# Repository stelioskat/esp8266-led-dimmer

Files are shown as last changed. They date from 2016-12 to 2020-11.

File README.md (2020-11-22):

# ESP8266 LED Dimmer (MQTT controlled)

1. [Layout](#layout)
  1. [Parts](#parts)
  2. [Schematic](#schematic)
2. [Firmware](#firmware)
  1. [MQTT](#mqtt)

This is a very simple wifi enabled (ESP8266 12e) LED dimmer for single colored LED strips. 

Its purpose was originally to be controlled by Node-RED (http://nodered.org) and node-red-contrib-homekit (https://flows.nodered.org/node/node-red-contrib-homekit) using MQTT events. Thus, one could control this with Apple Homekit.

Of course by using MQTT you can control it with whatever you like and not necessarily with Apple Homekit.

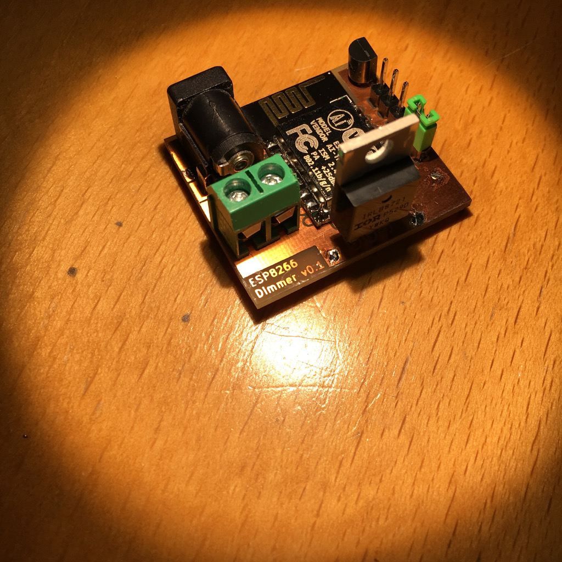
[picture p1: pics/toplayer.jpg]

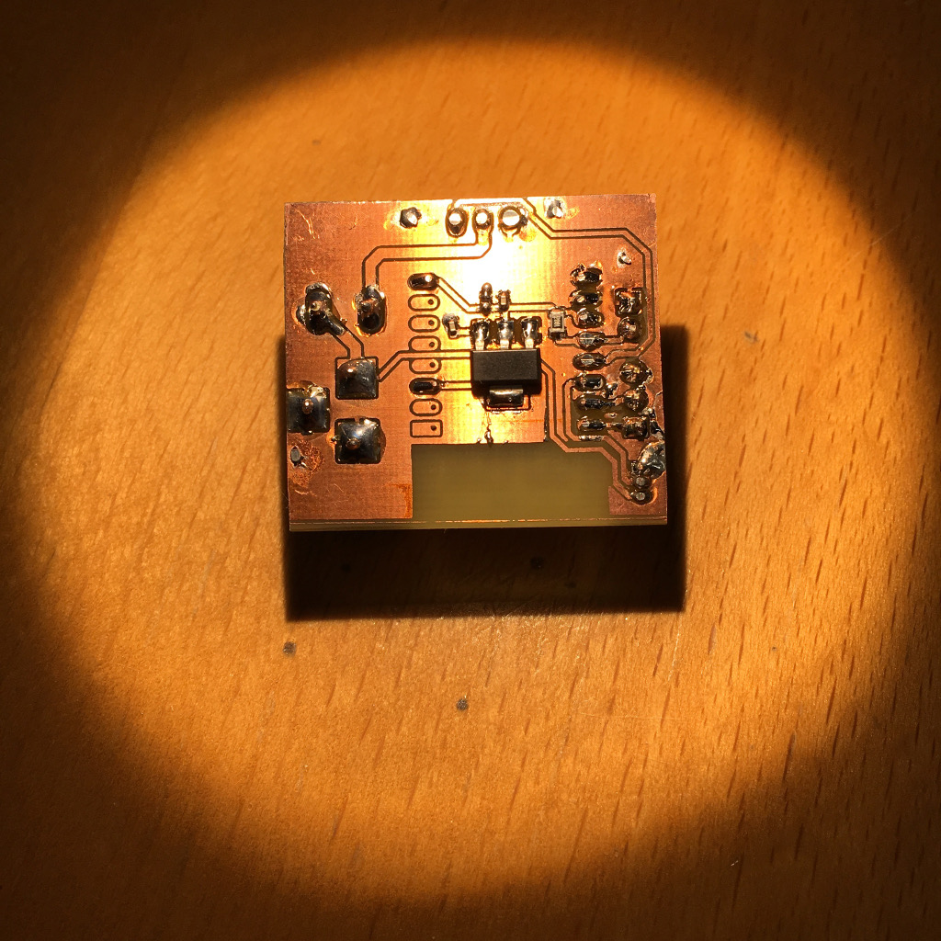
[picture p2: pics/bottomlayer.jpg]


## Layout

The layout is made with KiCad but I have also included an screenshot of the schematic, in case you want to make your own PCB with another software. You could simply produce this PCB for example by uploading the `ESPDimmer.kicad_pcb` file directly in [AISLER](https://go.aisler.net) .

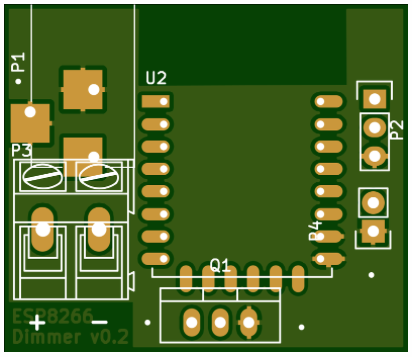
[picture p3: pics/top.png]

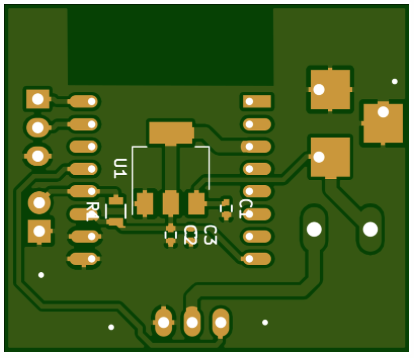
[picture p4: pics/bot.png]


### Parts
<table>
<tr>
  <th>
    Nr.
  </th>
  <th>
    Part
  </th>
  <th>
    Package
  </th>
  <th>
    Qty.
   </th>
</tr>
<tr>
  <td>1</td>
  <td>Capacitor 100nF</td>
  <td>0402</td>
  <td>2</td>
</tr>
<tr>
  <td>2</td>
  <td>Capacitor 1uF</td>
  <td>Package 0402</td>
  <td>1</td>
</tr>
<tr>
  <td>3</td>
  <td>Resistor 10k</td>
  <td>Package 0805</td>
  <td>1</td>
</tr>
<tr>
  <td>4</td>
  <td>Voltage regulator TLV1117</td>
  <td>SOT-223</td>
  <td>1</td>
</tr>
<tr>
  <td>5</td>
  <td>AK300-2 Terminal for LED strip</td>
  <td>-</td>
  <td>1</td>
</tr>
<tr>
  <td>6</td>
  <td>ESP8266-12E</td>
  <td></td>
  <td>1</td>
</tr>
<tr>
  <td>7</td>
  <td>Standard barrel jack for power supply</td>
  <td></td>
  <td>1</td>
</tr>
 <tr>
  <td>8</td>
  <td>30V Single N-Channel Power MOSFET</td>
  <td>TO-220</td>
  <td>1</td>
</tr>
</table>

### Schematic

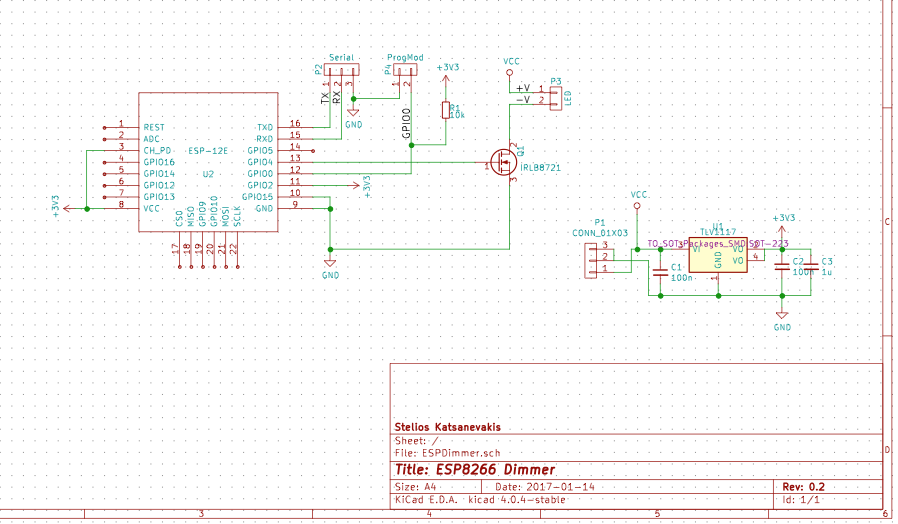
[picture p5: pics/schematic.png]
Schematic


## Firmware

The firmware can be compiled in Arduino IDE using the available ESP8266 package. In order to flash the firmware you will need a USB-to-Serial adapter such as the FTDI232 that I am using (https://github.com/jandelgado/arduino/wiki/FTDI232-USB-to-Serial-converter). Keep in mind that you will have to update the Wifi credentials and also the MQTT broker hostname and port to fit your own.

Of course, you could write your own firmware or you use another one since this is basically a breakout board.

### MQTT

The default firmware subscribes to the topic "/light/1" and expects the following JSON messages to control the LED strip and its brightness.

- Turn on command:
```
{"On":1}
```
- Turn off command:
```
{"On":0}
```
- Set brightness level:
```
{"Brightness":<A VALUE BETWEEN 0 AND 100>}
```

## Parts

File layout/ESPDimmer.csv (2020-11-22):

Id | Designator | Package | Quantity | Designation | Supplier and ref
1 | C1,C2 | C_0402 | 2 | 100n
2 | P2 | Socket_Strip_Straight_1x03 | 1 | Serial
3 | P4 | Socket_Strip_Straight_1x02 | 1 | ProgMod
4 | R1 | R_0805 | 1 | 10k
5 | U1 | SOT-223 | 1 | TLV1117
6 | P3 | AK300-2 | 1 | LED
7 | U2 | ESP-12E | 1 | ESP-12E
8 | Q1 | TO-220_Neutral123_Vertical | 1 | IRLB8721
9 | P1 | BARREL_JACK | 1 | CONN_01X03
10 | C3 | C_0402 | 1 | 1u

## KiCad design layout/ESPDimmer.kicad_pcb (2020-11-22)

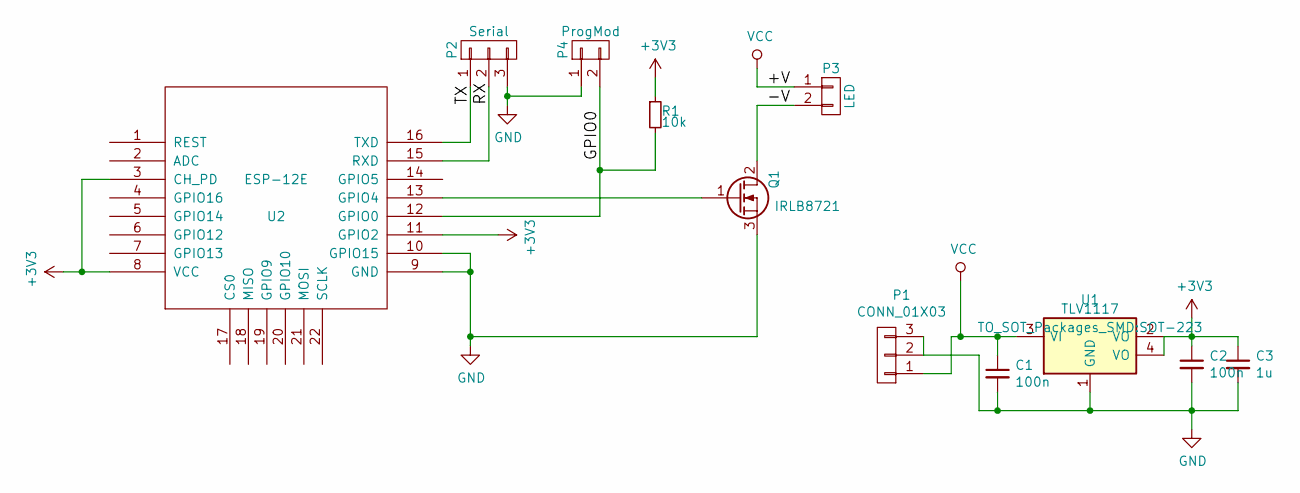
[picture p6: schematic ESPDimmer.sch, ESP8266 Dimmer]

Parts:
C1, C2: 100n; C_0402
C3: 1u; C_0402
P1: CONN_01X03; BARREL_JACK
P2: Serial; Socket_Strip_Straight_1x03
P3: LED; AK300-2
P4: ProgMod; Socket_Strip_Straight_1x02
Q1: IRLB8721; TO-220_Neutral123_Vertical
R1: 10k; R_0805
U1: TLV1117; SOT-223
U2: ESP-12E

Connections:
+3V3: C2.1, C3.1, R1.1, U1.2 (VO), U1.4 (VO), U2.3 (CH_PD), U2.8 (VCC), U2.11 (GPIO2)
/-V: P3.2, Q1.2 (D)
/GPIO0: P4.2, R1.2, U2.12 (GPIO0)
/RX: P2.2, U2.15 (RXD)
/TX: P2.1, U2.16 (TXD)
GND: C1.2, C2.2, C3.2, P1.2, P1.3, P2.3, P4.1, Q1.3 (S), U1.1 (GND), U2.9 (GND), U2.10 (GPIO15)
unnamed: Q1.1 (G), U2.13 (GPIO4)
VCC: C1.1, P1.1, P3.1, U1.3 (VI)

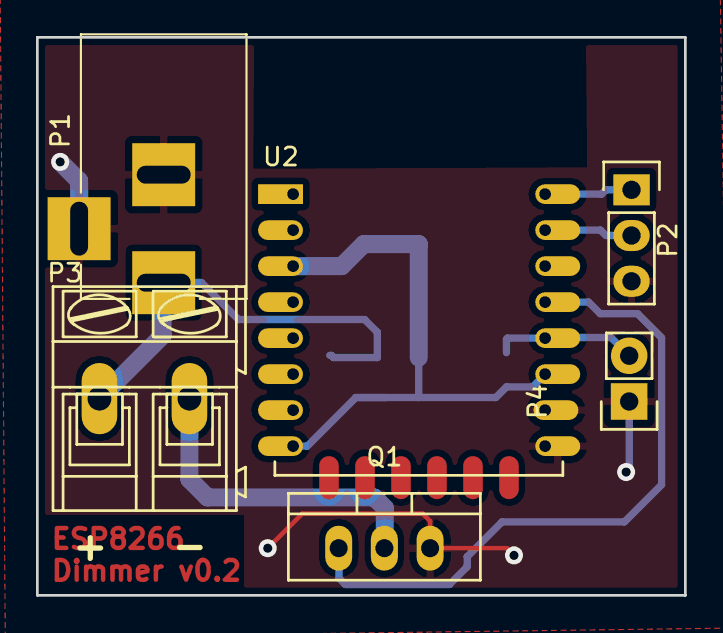
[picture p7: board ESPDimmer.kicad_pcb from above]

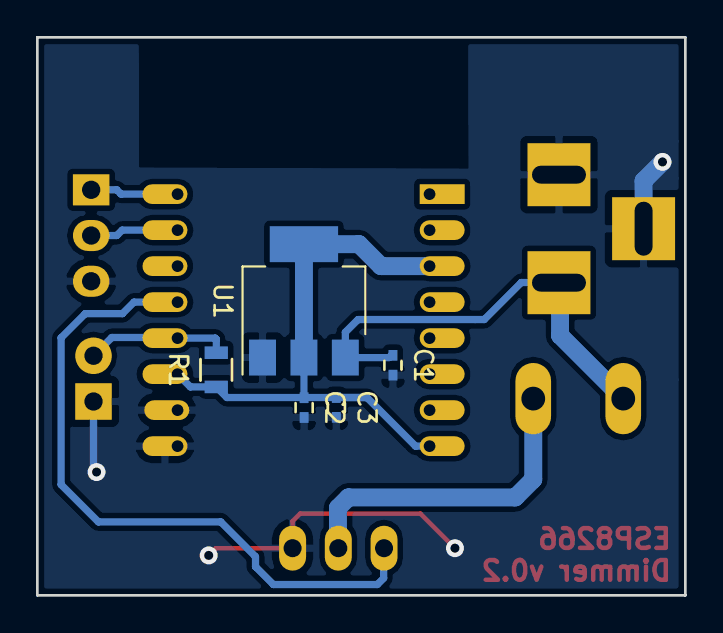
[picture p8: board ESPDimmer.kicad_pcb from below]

Board: 2 copper layers, 36.0 x 31.0 mm, 11 parts (5 on the bottom side), 8 nets.

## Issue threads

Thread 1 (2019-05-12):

two led strips

VOVAiS, 2019-05-12:
Hello.
Can version of your sketch in two led strips?

stelioskat, 2019-06-13:
Hi. Do you mean to drive them individually or just connect them in parallel?

VOVAiS, 2019-06-13:
drive them individually

stelioskat, 2019-06-14:
this would require a second transistor. You could e.g. replicate in GPIO5 the same exactly circuitry as you can see at GPIO4. Of course you would have to extend the firmware accordingly and ensure that your power supply (VCC) has enough power.

Closed 2019-06-14.

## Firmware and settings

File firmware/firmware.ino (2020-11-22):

#include <ESP8266WiFi.h>
#include "Adafruit_MQTT.h"
#include "Adafruit_MQTT_Client.h"

#define WLAN_SSID   "YOUR SSID"
#define WLAN_PASS   "YOUR PASSWORD"

#define SERVER      "minibian" // The hostname of the server where the MQTT broker is installed
#define SERVERPORT  1883 // The port of the MQTT broker

#define LED         4   // Pin controlling to the LED strip.


unsigned int i = 0;
unsigned int brightness = 1023;
bool led_on = false;

// Create an ESP8266 WiFiClient class to connect to the MQTT server.
WiFiClient client;

Adafruit_MQTT_Client mqtt(&client, SERVER, SERVERPORT);
Adafruit_MQTT_Subscribe onoffsw = Adafruit_MQTT_Subscribe(&mqtt, "/light/1");
Adafruit_MQTT_Publish status_mqtt = Adafruit_MQTT_Publish(&mqtt, "/light/1/status");

void setup() {
  // Initialization
  pinMode(LED, OUTPUT);
  
  Serial.begin(115200);
  Serial.println();
  Serial.println();

  // We start by connecting to a WiFi network
  Serial.print("Connecting to ");
  Serial.println(ssid);
  WiFi.begin(ssid, pass);
  
  while (WiFi.status() != WL_CONNECTED) {
    delay(500);
    Serial.print(".");
  }
  Serial.println("");
  
  Serial.println("WiFi connected");
  Serial.println("IP address: ");
  Serial.println(WiFi.localIP());

  // Setup MQTT subscription for onoff feed.
  mqtt.subscribe(&onoffsw);

  MQTT_connect();
  status_mqtt.publish("{\"On\":0, \"Brightness\":100}");
}


void loop() {
  // Ensure the connection to the MQTT server is alive (this will make the first
  // connection and automatically reconnect when disconnected).  See the MQTT_connect
  // function definition further below.
  MQTT_connect();

  while (mqtt.readSubscription(1000)) {

    // Turn the strip on
    if (strcmp((char *)onoffsw.lastread, "{\"On\":1}") == 0 && !led_on) {

      led_on = true;
      Serial.println(F("On"));
      i = 0;
      while (i < brightness) {
        analogWrite(LED, i);
        i += 2;
        delay(4);
      }

    }
    // Turn the strip off
    else if (strcmp((char *)onoffsw.lastread, "{\"On\":0}") == 0 && led_on) {

      led_on = false;
      Serial.println(F("Off"));
      while (i > 10) {
        analogWrite(LED, i);
        i -= 10;
        delay(20);
      }
      analogWrite(LED, 0);
      i = 0;

    }
    // Update the brightness value
    else if (strncmp((char *)onoffsw.lastread, "{\"Brightness\":", 14) == 0 ) {

      Serial.print(F("Brightness: "));
      unsigned int l = strlen((char *)onoffsw.lastread);
      onoffsw.lastread[l - 1] = '\0'; // overwrite the ending bracket
      unsigned int bright_perc = atoi((char *)onoffsw.lastread + 14);
      Serial.println(bright_perc);
      unsigned int new_brightness = 1023 * bright_perc / 100;
      if (new_brightness > 1023) new_brightness = 1023;
      if (led_on) {
        if (new_brightness > i) {
          while (i < new_brightness) {
            analogWrite(LED, i);
            i += 2;
            delay(4);
          }
          analogWrite(LED, new_brightness);
          i = new_brightness;
        }
        else {
          while (i > new_brightness) {
            analogWrite(LED, i);
            i -= 1;
            delay(2);
          }
          analogWrite(LED, new_brightness);
          i = new_brightness;
        }
      }

      brightness = new_brightness;
    }
  }
}


// Function to connect and reconnect as necessary to the MQTT server.
// Should be called in the loop function and it will take care if connecting.
void MQTT_connect() {
  int8_t ret;

  // Stop if already connected.
  if (mqtt.connected()) {
    return;
  }

  Serial.print(F("Connecting to MQTT... "));

  uint8_t retries = 3;
  while ((ret = mqtt.connect()) != 0) { // connect will return 0 for connected
    Serial.println(mqtt.connectErrorString(ret));
    Serial.println(F("Retrying MQTT connection in 5 seconds..."));
    mqtt.disconnect();
    delay(5000);  // wait 5 seconds
    retries--;
    if (retries == 0) {
      // basically die and wait for WDT to reset me
      while (1);
    }
  }
  Serial.println(F("MQTT Connected!"));
}

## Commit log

2016-12-30 Added version 0.1 of the PCB
    The dimmer also features an optional DS18B20 thermometer, because why not? :D
    [ESPDimmer.kicad_pcb, ESPDimmer.sch]
2016-12-30 Updated part names and corrected the power supply traces that were shorted!
    [ESPDimmer.kicad_pcb, ESPDimmer.sch]
2016-12-30 Added some vias for better grounding
    [ESPDimmer.kicad_pcb]
2016-12-30 Updated capacitors and other small changes
    [ESPDimmer.kicad_pcb, ESPDimmer.sch]
2016-12-31 Added pull-up resistor needed for the OneWire communication with the DS18B20 thermometer.
    [ESPDimmer.kicad_pcb, ESPDimmer.sch]
2016-12-31 Added some pictures
    [ESPDimmer.sch]
2016-12-31 Create README.md with schematic screenshot
2016-12-31 Update firmware to check if the led strip is already on/off and correspondingly apply new changes or not
2017-01-01 Added support for the Dallas DS18B20 thermometer which is on board.
    The firmware broadcasts the current temperature every 5 seconds with an MQTT message with topic “/temp/1”
2017-01-01 Increased temperature reading update interval to 5 minutes and added more comments.
2020-11-22 The dimmer now publishes a MQTT message with its current status, once it connects to the MQTT broker
    [firmware.ino]
2020-11-22 Removed thermometer because its readings were incorrect due to the thermal release of the voltage regulator
    [ESPDimmer.csv, ESPDimmer.kicad_pcb, ESPDimmer.sch]
2020-11-22 Some cleanup and small fixes
    [firmware.ino]
